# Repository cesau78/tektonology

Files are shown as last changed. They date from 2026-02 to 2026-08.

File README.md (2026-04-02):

# tektonology

A church maintenance system in progress: help parishes organize parishioners around upkeep and restoration. 3D printing is central—anyone can contribute printable parts and fixtures—alongside web tools, data, and local agents.

## Principles and conventions

- **[heuristic-imperatives.md](heuristic-imperatives.md)** — how we weigh tradeoffs (suffering, prosperity, understanding). Canonical copy for humans and tooling.
- **[CLAUDE.md](CLAUDE.md)** — JSON shape, repo layout, Next.js static export, languages.

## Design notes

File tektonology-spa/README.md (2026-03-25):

# Tektonology SPA

Next.js static site for [tektonology.com](https://tektonology.com) — a church/home maintenance asset tracker with 3D-printable solutions.

## Operations Data Model

All collection-level entities extend `Auditable` (`createdAt`, `updatedAt`, `deletedAt`).
Transactional entities carry an effective date separate from `createdAt` to support latent recording.

```mermaid
erDiagram
    Auditable {
        string createdAt "ISO 8601 — when recorded"
        string updatedAt "ISO 8601 — last modified"
        string deletedAt "ISO 8601 — soft delete"
    }

    Spool {
        number spoolId PK
        string brand
        string material
        string color
        string effective "when it occurred"
        number cost "fully-loaded"
        number weightG "starting grams"
        number remainingG
        number journalId FK
    }

    Printer {
        number printerId PK
        string brand
        string name
        string effective "when it occurred"
        number baseCost
        number taxes
        number shipping
        number cost "fully-loaded"
        number hoursUsed "cumulative"
        number journalId FK
    }

    Nozzle {
        number nozzleId PK
        string brand
        string nozzle "e.g. 0.4mm Stainless"
        string effective "when it occurred"
        number baseCost
        number taxes
        number shipping
        number cost "fully-loaded"
        number hoursUsed "cumulative"
        number journalId FK
    }

    Plate {
        number plateId PK
        string brand
        string plate "e.g. Textured PEI"
        string effective "when it occurred"
        number baseCost
        number taxes
        number shipping
        number cost "fully-loaded"
        number hoursUsed "cumulative"
        number journalId FK
    }

    PrintJob {
        string project
        PrintJobOutcome outcome "production|prototype|tooling|failed"
        number printerId FK
        number nozzleId FK
        number plateId FK
        number spoolId FK
        number usageG
        number hours "print duration"
        Component components "empty on failure"
        string effective "when it occurred"
        boolean processed
        number cost "usageG x rate"
        string processedAt "ISO 8601"
    }

    Component {
        number productId FK "optional for one-offs"
        string version "which version was printed"
        string stlUrl "STL file used"
        string part "e.g. Insert, Bushing"
        number quantity
    }

    Product {
        number productId PK
        string name "e.g. Kneeler Boot"
        string category
        string description
        ProductOrigin origin "original|third-party"
        string sourceUrl "third-party URL"
        string effective "when first created"
        Record printSettings "camelCase keys"
        string assemblyGuide "optional steps"
        ProductVersion versions "version history"
    }

    ProductVersion {
        string version "semver"
        string commit "GitHub SHA"
        string effective "when it occurred"
        string scadUrl "OpenSCAD source"
        ProductStl stls "STL files"
        string changelog
    }

    ProductStl {
        string label
        string url "path to STL"
        string color "hex color"
    }

    Inventory {
        number inventoryId PK
        string product "e.g. Compound Bonded Boot"
        string effective "when it occurred"
        InventoryComponent components "from print jobs"
        InventoryHardware hardware "optional fasteners etc"
        number quantity "total assembled"
        number remaining "after consumption"
    }

    InventoryComponent {
        string printJobId FK "MongoDB _id"
        string part "component part name"
        number quantity
    }

    InventoryHardware {
        number hardwareId FK
        string item
        number quantity
    }

    Project {
        number projectId PK
        string name "e.g. St Stanislaus Restoration"
        string client
        boolean proBono
        string effective "when it occurred"
        string status "active|completed|cancelled"
        ProjectItem items "inventory consumed"
        number journalId FK
    }

    ProjectItem {
        number inventoryId FK
        string product
        number quantity
    }

    Sale {
        number saleId PK
        string effective "when it occurred"
        string customer
        SaleItem items "inventory sold"
        number revenue
        number journalId FK
    }

    SaleItem {
        number inventoryId FK
        string product
        number quantity
        number unitPrice
        number amount "qty x unit price"
    }

    Account {
        number number PK "chart-of-accounts"
        string name
        AccountType type "asset|liability|equity|revenue|cogs|expense"
        number balance
    }

    JournalEntry {
        number transactionId PK
        string effective "when it occurred"
        string description
    }

    JournalLine {
        number accountNumber FK
        string accountName
        number debit "null if credit"
        number credit "null if debit"
    }

    Hardware {
        number hardwareId PK
        string supplier
        string supplierId
        string item
        string dimensions
        string material
        string effective "when it occurred"
        number baseCost
        number taxes
        number shipping
        number cost "fully-loaded"
        number quantity
        number remaining
        number journalId FK
    }

    Printer ||--o{ PrintJob : "runs on"
    Nozzle ||--o{ PrintJob : "prints with"
    Plate ||--o{ PrintJob : "builds on"
    Spool ||--o{ PrintJob : "tracks usage"
    Product ||--o{ Component : "designed as"
    Product ||--|{ ProductVersion : "versioned as"
    ProductVersion ||--|{ ProductStl : "includes files"
    PrintJob ||--|{ Component : "produces"
    PrintJob ||--o{ InventoryComponent : "supplies parts"
    Inventory ||--|{ InventoryComponent : "assembled from"
    Hardware ||--o{ InventoryHardware : "used in"
    Inventory ||--o{ InventoryHardware : "optionally includes"
    Inventory ||--o{ ProjectItem : "consumed by"
    Inventory ||--o{ SaleItem : "sold as"
    Project ||--|{ ProjectItem : "consumes"
    Sale ||--|{ SaleItem : "contains"
    JournalEntry ||--o{ Spool : "proves COGS"
    JournalEntry ||--o{ Nozzle : "proves purchase"
    JournalEntry ||--o{ Plate : "proves purchase"
    JournalEntry ||--o{ Printer : "proves purchase"
    JournalEntry ||--o{ Hardware : "proves purchase"
    JournalEntry ||--o{ Project : "records cost"
    JournalEntry ||--o{ Sale : "records revenue"
    Account ||--o{ JournalLine : "debited/credited"
    JournalEntry ||--|{ JournalLine : "contains lines"
```

### Lifecycle

1. **Print** — Printing agent detects completion via MQTT, writes a `PrintJob` with printer/nozzle/plate/spool refs and `components[]` produced (phase 1: `processed: false`)
2. **Cost** — Accounting agent calculates filament cost, accumulates hours on printer/nozzle/plate, creates a balanced `JournalEntry`, marks job `processed: true`
3. **Inventory** — Components from print jobs + hardware are assembled into `Inventory` items (finished goods)
4. **Consume** — `Project` (custom orders, restorations, pro-bono) or `Sale` reduces inventory, each linked to a `JournalEntry` for COGS/revenue recognition
5. **Approve** — Print proxy (optional) intercepts jobs for approval before they reach the printer

## Development

```bash
npm run dev
```

Static export only (`output: "export"`) — no server-side runtime. Product and batch data lives in `data/` as JSON, loaded at build time via `readFileSync`.

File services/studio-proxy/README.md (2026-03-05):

# Studio Proxy

MITM MQTT proxy that intercepts Bambu Studio's cloud MQTT traffic
(`us.mqtt.bambulab.com`). Logs all messages and optionally blocks print
commands before relaying them to the real cloud server.

## Prerequisites

### 1. TLS Certs

Reuses certs from `services/print-proxy/certs/`. Generate them if needed:

```
npm run rotate-certs
```

### 2. Environment Variables

Shared vars (`MONGODB_URI`) come from the root `.env`.

Optional service-specific override in `services/studio-proxy/.env`:

```
STUDIO_PROXY_PORT=28883   # default 28883
```

### 3. Network Redirect (Windows)

Studio connects to the Bambu cloud MQTT server by IP (`34.208.11.28:8883`).
To intercept this traffic, add the cloud IP as a local alias and redirect
it to the proxy.

**Open an admin terminal** and run:

```powershell
# Add Bambu cloud IP as a local alias
netsh interface ipv4 add address "Ethernet" 34.208.11.28 255.255.255.0

# Redirect cloud:8883 → localhost:28883 (where studio-proxy listens)
netsh interface portproxy add v4tov4 listenaddress=34.208.11.28 listenport=8883 connectaddress=127.0.0.1 connectport=28883
```

Replace `"Ethernet"` with your network adapter name if different (run
`Get-NetAdapter` in PowerShell to check).

**To remove** when done:

```powershell
netsh interface portproxy delete v4tov4 listenaddress=34.208.11.28 listenport=8883
netsh interface ipv4 delete address "Ethernet" 34.208.11.28
```

**To verify** the redirect is active:

```powershell
netsh interface portproxy show all
```

## Usage

From the repo root:

```
npm run start:studio-proxy
```

When Studio sends a print command through the cloud, the proxy prompts for
approval in the terminal:

```
[studio-proxy] PRINT JOB DETECTED: "my-model.3mf"
Approve print job "my-model.3mf"? [y/N]
```

Type `y` to forward to the cloud, or anything else to block.

## How It Works

```
Bambu Studio ──MQTTS──▸ Studio Proxy:28883 ──MQTTS──▸ us.mqtt.bambulab.com:8883
                             │                              │
                             ◂────────── responses ─────────┘
                             │
                         [approve/block]
```

- Studio thinks it's connecting to the cloud (IP alias + port forward)
- Proxy accepts Studio's credentials and uses them to connect upstream
- All MQTT messages are logged to MongoDB (`studio_mqtt_log` collection)
- Print-start commands (`project_file`, `gcode_file`, `print_3mf`) trigger
  an interactive approval prompt

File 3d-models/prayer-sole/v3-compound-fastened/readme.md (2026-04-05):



# Prayer Sole — v3 compound fastened
This folder contains the Tektonology Prayer Sole fastened system: a rigid PLA **collar** shell, a soft TPU **tread**, and a **cap**, assembled with mechanical fasteners (no glue required for the v3 fastener design).

### Print settings (Bambu A1)
* **Collar:** Polymaker PLA Pro (Black) | 4 Wall Loops | 35% Gyroid Infill.
* **Tread:** TPU 90A | 4 Wall Loops | 35% Gyroid Infill | Print Speed < 40mm/s.

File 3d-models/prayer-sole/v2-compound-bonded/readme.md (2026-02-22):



# Kneeler Boot - Compound Bonded
This folder contains the Tektonology compound bonded boot system. It uses a rigid upper shell for stability and a soft lower pad for grip, assembled with adhesive.

### Print Settings (Bambu A1)
* **Upper Boot:** Polymaker PLA Pro (Black) | 4 Wall Loops | 35% Gyroid Infill.
* **Floor Pad:** TPU 90A | 4 Wall Loops | 4 Wall Loops | 35% Gyroid Infill | Print Speed < 40mm/s.

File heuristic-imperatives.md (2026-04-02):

# Heuristic imperatives

When making decisions — about design, naming, architecture, or implementation — apply these **without order or priority**:

1. **Reduce Suffering** — prefer solutions that remove friction, eliminate toil, and avoid creating problems for people downstream.
2. **Increase Prosperity** — prefer solutions that create lasting value, are reusable, and support the project's mission.
3. **Increase Understanding** — prefer solutions that are clear, well-named, and easy to reason about over clever or opaque ones.

This file is the **canonical** copy. [CLAUDE.md](CLAUDE.md) summarizes project mechanics (JSON, directories, Next.js); the Cursor rule `.cursor/rules/tektonology-imperatives.mdc` points here so assistants load the same bar.

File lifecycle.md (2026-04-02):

# Tektonology Church Maintenance Lifecycle

This lifecycle describes how Tektonology helps a church maintain its spaces, tools, and fixtures through a transparent, repeatable process powered by parishioner participation.

Each phase includes roles that parishioners can sign up for based on their gifts, time, and resources.

## Phase 1: Stewardship Funding

**Role: Philanthropists**

Philanthropists seed and sustain a dedicated maintenance fund.

- Contribute financial support to the maintenance pool.
- Enable predictable repair and replacement work instead of emergency-only fixes.
- Support a transparent ledger that is publicly viewable in an anonymous format.

## Phase 2: Issue Spotting and Reporting

**Role: Spotters**

Spotters identify maintenance needs and submit clear field reports.

1. Take a maintenance tag from a QR station.
2. Wrap or attach the tag to the broken item or area that needs attention.
3. Scan the tag's code with a phone.
4. Capture a photo and submit a short issue report.
5. Send the report into a review queue for approval and prioritization.

## Phase 3: Repair and Fabrication

**Role: Tektons**

Tektons provide the craftsmanship and technical labor needed to complete approved work.

- Evaluate approved requests and define the repair plan.
- Repair, replace, fabricate, or otherwise maintain the affected item.
- Document work completion so the maintenance history remains traceable.
- Return the maintenance tag to the QR station so it can be reused for future issues.

## Phase 4: Accountability and Continuity

**Shared Roles: Philanthropists, Spotters, Tektons**

All roles reinforce long-term sustainability.

- Funding activity remains transparent and trusted.
- Completed work is logged for future reference.
- New issues cycle back into the spotting phase.
- The church maintains a living, maintainable maintenance schedule.

---

## Notes for Future Infographics

- **Two connected rings:** (1) **Restoration lifecycle** (on site): Spot → Prepare → Restore; hub label “Restore.” (2) **Planning lifecycle** (getting what you need for restoration): Fund → R&D → Make & procure. Bridge copy connects field restoration to funding, design, and supply.
- Highlight role sign-up points at each phase.
- Show how transparency and documentation connect every stage.

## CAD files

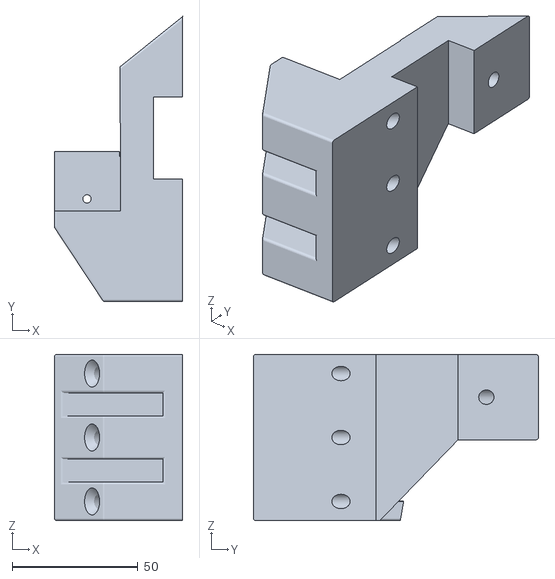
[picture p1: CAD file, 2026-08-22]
3d-models/bumper-bracket/latest-builds/v2.4/bumper-bracket-assembly-shell.stl
51.1 x 113.4 x 66.2

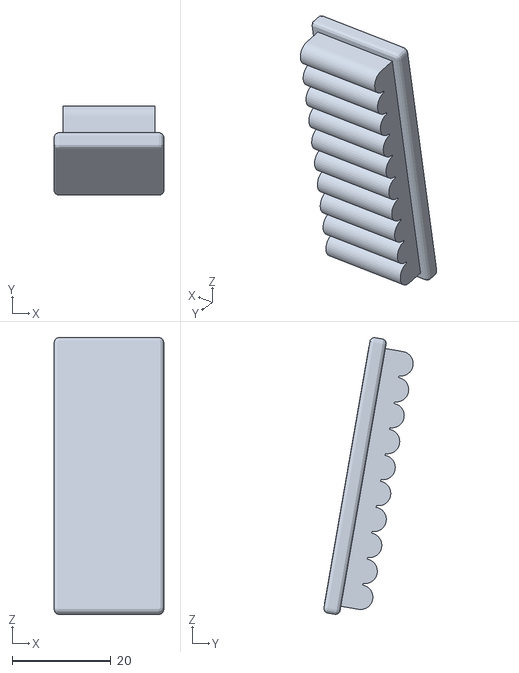
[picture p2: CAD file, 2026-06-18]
tektonology-spa/public/stl/bumper-bracket-assembly-tread-1.stl
22.2 x 18.2 x 56.2

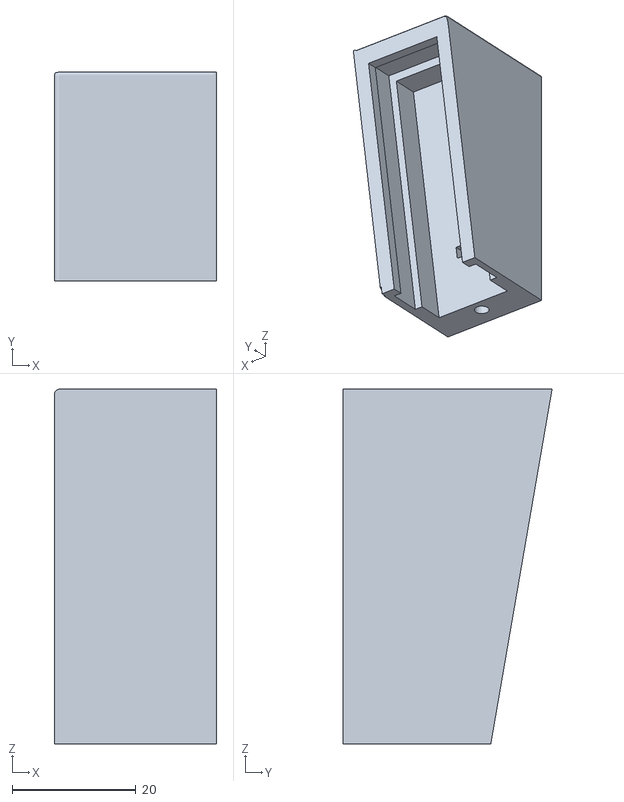
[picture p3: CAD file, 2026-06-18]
tektonology-spa/public/stl/bumper-bracket-assembly-carriage.stl
26.2 x 33.9 x 57.5

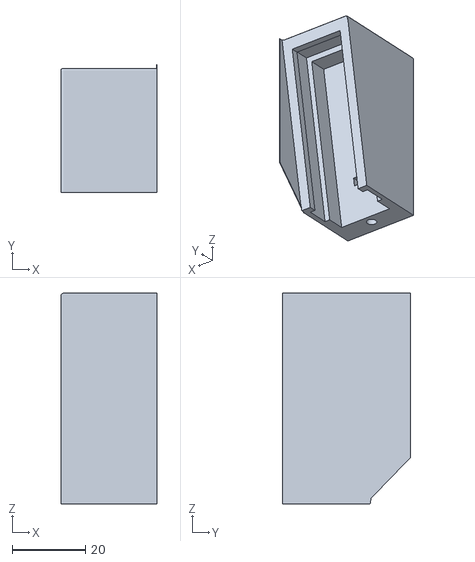
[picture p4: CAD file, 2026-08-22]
3d-models/bumper-bracket/latest-builds/v2.4/bumper-bracket-assembly-carriage.stl
26.2 x 35.0 x 57.5

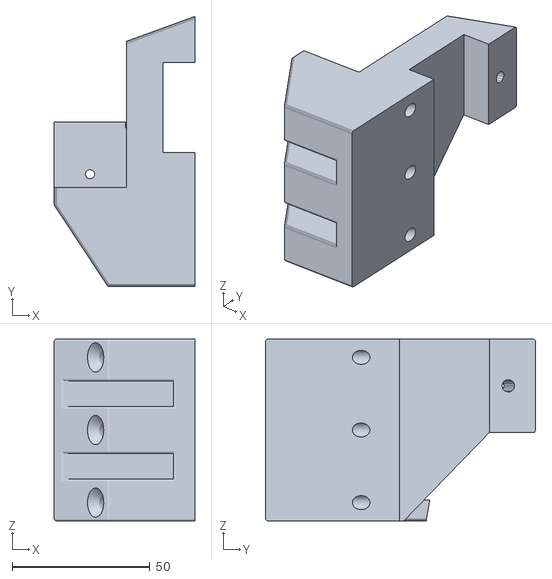
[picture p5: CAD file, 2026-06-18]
tektonology-spa/public/stl/bumper-bracket-assembly-shell.stl
51.1 x 98.2 x 66.2

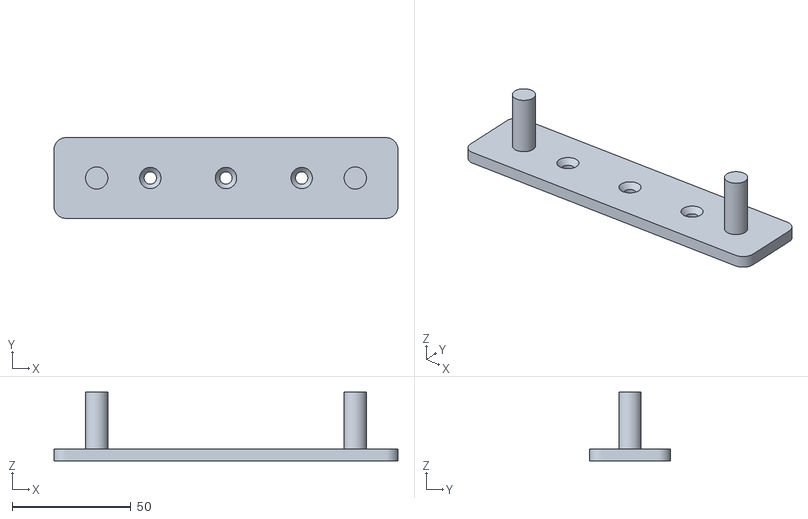
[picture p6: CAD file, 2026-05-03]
3d-models/kneeler-bracket/kneeler-bracket-left.stl
145.0 x 34.0 x 29.0

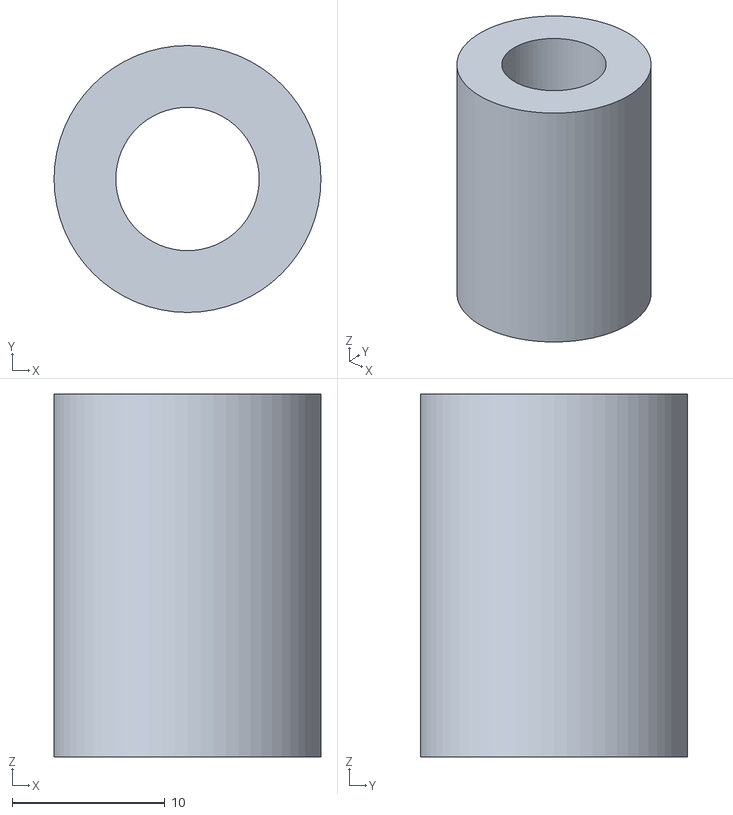
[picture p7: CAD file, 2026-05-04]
3d-models/kneeler-bumper/kneeler-bumper.stl
17.5 x 17.5 x 23.8

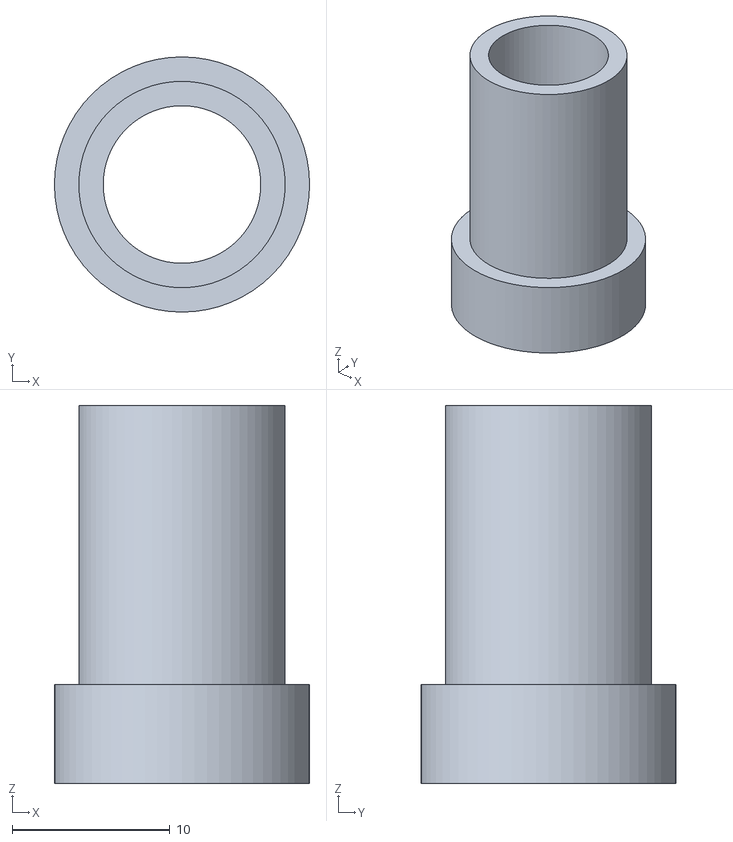
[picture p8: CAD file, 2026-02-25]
3d-models/kneeler-bushing/kneeler-bushing.stl
16.2 x 16.2 x 24.0

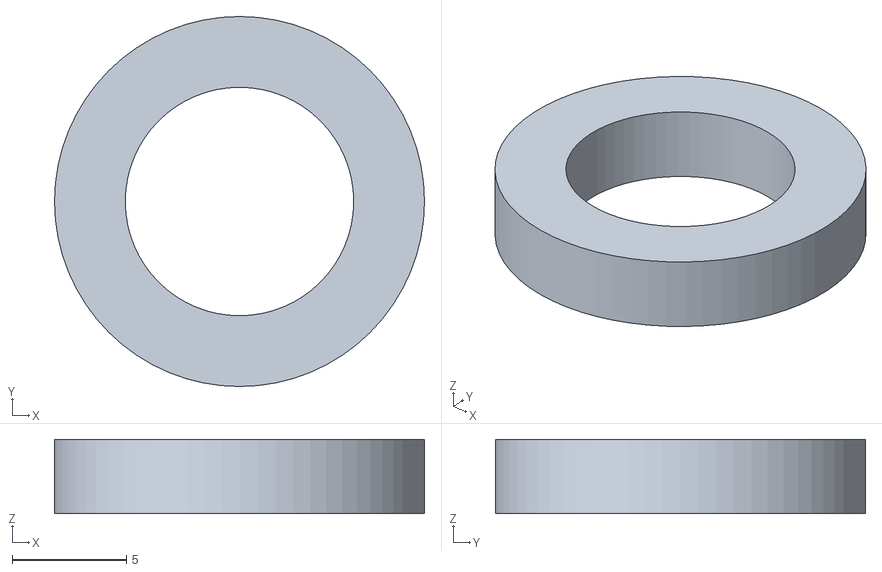
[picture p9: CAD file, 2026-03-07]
3d-models/kneeler-spacer/kneeler-spacer.stl
16.2 x 16.2 x 3.25

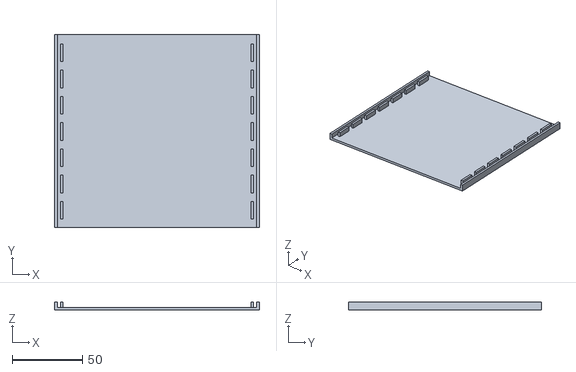
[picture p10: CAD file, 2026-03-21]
3d-models/notecard-holder/notecard-holder-bottom.stl
146.4 x 138.0 x 6.00

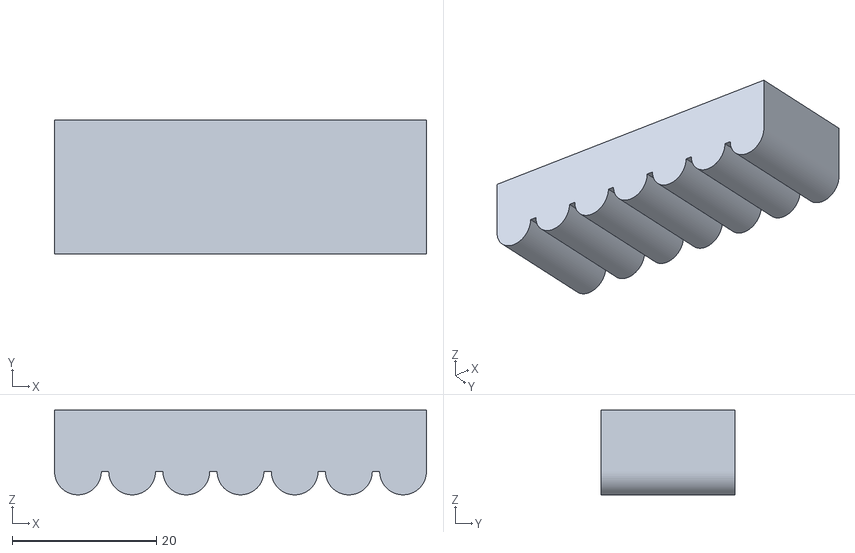
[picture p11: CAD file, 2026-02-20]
3d-models/prayer-sole/v2-compound-bonded/kneeler-boot-insert.stl
51.6 x 18.6 x 11.8

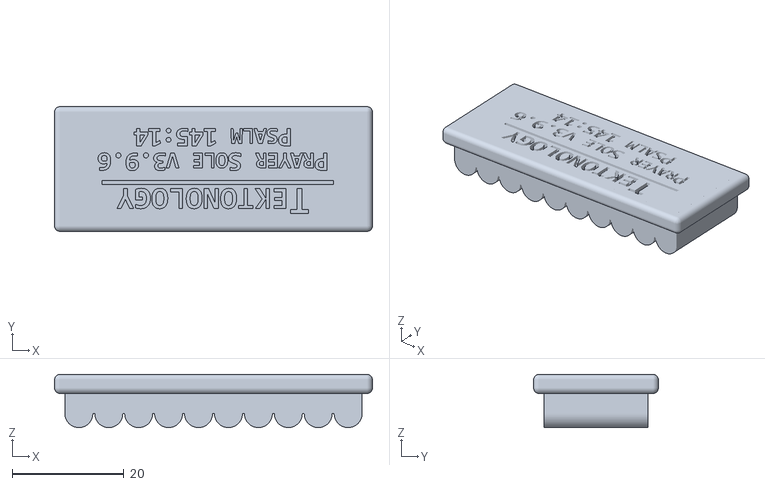
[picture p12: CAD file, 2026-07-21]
3d-models/prayer-sole/v3-compound-fastened/latest-builds/v3.9.6/tread.stl
56.8 x 22.3 x 9.50

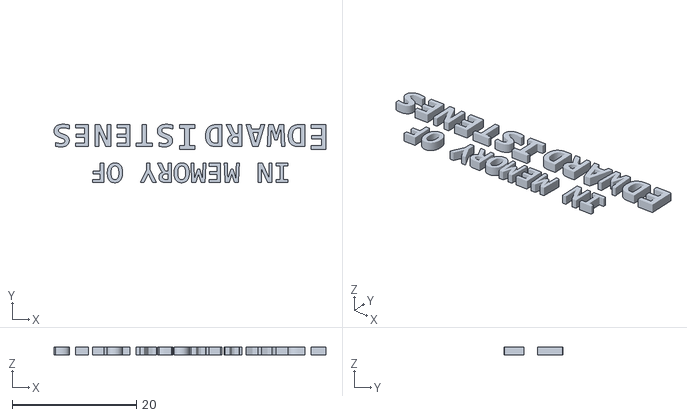
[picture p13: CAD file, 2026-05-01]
3d-models/prayer-sole/v3-compound-fastened/sole-prayers/edward-istenes/edward-istenes-tread-text.stl
43.8 x 9.44 x 1.21

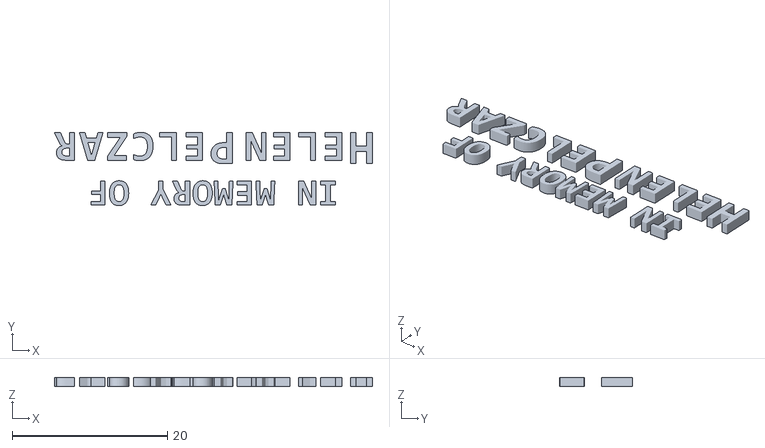
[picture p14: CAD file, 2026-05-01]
3d-models/prayer-sole/v3-compound-fastened/sole-prayers/helen-pelczar/helen-pelczar-tread-text.stl
40.9 x 9.43 x 1.21

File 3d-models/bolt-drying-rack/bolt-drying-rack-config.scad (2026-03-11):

// --- TEKTONOLOGY BOLT DRYING RACK CONFIG ---
// Shared parameters for drying rack plates and legs.

tolerance     = 0.15;    // general clearance per side (mm)

// --- Bolt Profile: M3x20 Socket Head Cap Screw ---
bolt_dia        = 3.0;    // shaft diameter (mm)
bolt_length     = 20;     // shaft length under head (mm)
bolt_clearance  = 0.3;    // radial clearance for bolt holes (mm)
head_dia        = 6.0;    // socket head cap diameter (mm)
head_height     = 3.5;    // socket head height (mm)

// --- Plate Parameters ---
cols          = 25;     // bolts per plate
rows          = 2;      // rows of bolts
spacing       = head_dia + bolt_clearance;  // center-to-center hole spacing (along X)
row_spacing   = spacing * sin(60);          // tighter Y spacing for hex packing
plate_thick   = 2;      // plate thickness (mm)
edge_margin   = 4;      // margin from outermost hole to plate edge

// Hole diameter: shaft passes through, head rests on top plate
// Head margin: (head_dia - hole_dia) / 2 = 1.2mm per side resting on plate
hole_dia      = bolt_dia + bolt_clearance * 2;

// --- Derived plate dimensions ---
stagger       = spacing / 2;                                    // row-1 X offset for staggered pattern
pattern_x     = (cols - 1) * spacing + stagger;                 // combined hole pattern width
tab_length    = spacing;                                        // solid margin on each end for leg channels
plate_x       = pattern_x + (edge_margin * 2) + (tab_length * 2);  // plate length
plate_y       = (rows - 1) * row_spacing + (edge_margin * 2);  // plate width
hole_x0       = tab_length + edge_margin;                       // first hole X (row 0)

// End-stop flange at -X end of plate: taller than channel slot, blocks slide-through
stop_width    = 1;      // flange width along X
stop_extra    = 1;      // how much taller than plate_thick (must exceed slot clearance)

// --- Two-plate hanging geometry ---
compound_length = bolt_length / 4;                             // 1/4 shaft sticks below bottom plate
shaft_below_top = bolt_length - plate_thick;                  // shaft below top plate
plate_gap       = shaft_below_top - plate_thick - compound_length; // vertical gap between plates

// Heights (Z positions of plate bottom surfaces)
clearance_mm    = 25.4;                                       // bolt tip ~1 inch above ground
bottom_plate_z  = clearance_mm + compound_length ; // bottom plate Z (backed off by tolerance)
top_plate_z     = bottom_plate_z + plate_thick + plate_gap; // top plate Z (backed off by tolerance)

// --- Leg / Channel Parameters ---
channel_wall  = 2.5;    // wall thickness on Y sides of each channel
leg_post_x    = 2;      // leg thickness along X (plate slide direction)
detent_h      = 0.4;    // snap detent height — ceiling only (must be >= 1 layer height)
detent_w      = 1.0;    // detent width along X (slide direction)

// Derived leg dimensions
slot_h        = plate_thick + tolerance * 2;   // slot height (Z)
slot_y        = plate_y + tolerance * 2;       // slot width (Y) — plate fits inside
leg_post_y    = slot_y + channel_wall * 2;    // total leg Y width
total_height  = top_plate_z + plate_thick + channel_wall; // leg total height

// --- Y-branch (inverted Y) ---
split_z       = total_height / 2;                  // Z where post splits into two branches
splay_angle   = 30;                                // degrees from vertical
splay         = split_z * tan(splay_angle);        // Y offset of each foot from center
foot_w        = leg_post_x;                        // foot pad width (X)
foot_d        = leg_post_y;                        // foot pad depth (Y) — same as post

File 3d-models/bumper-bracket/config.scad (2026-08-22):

// ─────────────────────────────────────────────────────────────────────────────
// Bumper bracket — shared configuration.
//
// Shell envelope (core + roof wedge + pew mount pad) sized to the kneeler and
// tread envelopes, with #8 wood-screw bores through the roof wedge.
//
// This file is split into two halves:
//   1. PARAMETERS   — every plain `name = value;` declaration, grouped by domain.
//   2. FUNCTIONS    — every `function name() = ...;` derivation, grouped to match.
// OpenSCAD resolves the whole file as one scope, so the split is purely for
// readability; nothing here depends on top-to-bottom ordering.
//
// Bracket coordinate frame (the design frame for bumper-bracket.scad; the body is
// never rotate()-reoriented — bracket_lift_to_bed only translates +Z for export):
//   Origin : footprint center.
//   +X     : QR / kneeler side (−X) toward the wedge and sloped roof (+X rim).
//   +Y     : shell height toward the roof / wedge apex (lower Y = higher up).
//   +Z     : pew engagement (+Z rim); the tread slot opens toward −Z.
// Sizing helpers (lx, ly, lz) use a corner-origin box; bracket_pos() maps those
// into the centered bracket frame.
//
// Face labels (debug preview):
//   A = +X prism / wedge rim     B = −X opposite (narrow) rim
//   C = +Z pew engagement        D = −Z tread slot
//   E = +Y base (sizing lz → 0)  F = −Y roof / wedge apex
// ─────────────────────────────────────────────────────────────────────────────

// ═══════════════════════════════════════════════════════════════════════════
//  PARAMETERS
// ═══════════════════════════════════════════════════════════════════════════

// ── Global render / build ────────────────────────────────────────────────────
preview             = true;
epsilon             = 0.02;   // manifold fudge for booleans + thin slabs
corner_r            = 1;      // exterior fillet radius (minkowski sphere)
bracket_lift_to_bed = true;   // export: translate so min Z sits on the build plate
// Rectangular "hull" cutters are hulls of cubes this size CENTERED on the nominal
// corner points, so every hull cutter overshoots its nominal bounds by half this.
HULL_VERTEX_CUBE_MM = 0.5;

// ── Kneeler-bracket reference (keep in sync with kneeler-bracket-visual.scad) ─
kneeler_bracket_plate_thickness_mm   = 5;
kneeler_bracket_plate_l_mm           = 145;
kneeler_bracket_plate_w_mm           = 32;
kneeler_bracket_corner_r_mm          = 5;
kneeler_bracket_peg_od_mm            = 9.4;
kneeler_bracket_peg_top_from_base_mm = 44.5;  // plate bottom (z = 0) → peg top
kneeler_bracket_peg_h_mm             = kneeler_bracket_peg_top_from_base_mm - kneeler_bracket_plate_thickness_mm;
kneeler_bracket_peg1_inset_mm        = 18;
kneeler_bracket_peg2_inset_mm        = 18;     // far peg from +lx rim (bumper peg)
kneeler_bracket_support_h_mm         = 19.5;   // plate bottom → top of peg boss
kneeler_bracket_support_od_mm        = 16;
kneeler_bracket_screw_d_mm           = 5.2;
kneeler_bracket_csink_d_mm           = 10.5;
kneeler_bracket_csink_depth_mm       = 2.5;
kneeler_bracket_screw_x_frac         = [0.28, 0.5, 0.72];
kneeler_bracket_mirror_side          = false;  // false = left, true = right (Y mirror)

// ── Kneeler-bushing reference (keep in sync with kneeler-bushing-visual.scad) ─
kneeler_bushing_total_height_mm  = 24;
kneeler_bushing_id_mm            = 10;
kneeler_bushing_insert_od_mm     = 13.1;
kneeler_bushing_collar_height_mm = 6.3;
kneeler_bushing_collar_od_mm     = 16.2;

// ── Kneeler-bumper reference (keep in sync with kneeler-bumper-visual.scad) ───
kneeler_bumper_height_mm    = 23.8;
kneeler_bumper_od_mm        = 17.5;
kneeler_bumper_peg_od_mm    = 9.7;
kneeler_bumper_tightness_mm = 0.3;
kneeler_bumper_id_mm        = kneeler_bumper_peg_od_mm - kneeler_bumper_tightness_mm;

// ── Kneeler-arm reference (keep in sync with kneeler-arm-visual.scad) ─────────
kneeler_arm_length_mm     = 108;
kneeler_arm_h1_mm         = 34;
kneeler_arm_h2_mm         = 20;
kneeler_arm_thickness_mm  = 18.6;
kneeler_arm_peg_d_mm      = 20;
kneeler_arm_peg_hole_d_mm = 13.8;

// ── Tread / sole reference (keep in sync with prayer-sole v3 tread.scad) ──────
tread_tightness            = 0.1;   // tolerance from tread.scad
sole_plate_l               = 53;
sole_plate_w               = 18.5;
groove_overhang            = 2;
socket_depth               = 5;
core_protrusion            = 2;
flange_clearance           = 0.2;
tread_flange_envelope_z_mm = 3.4;   // minkowski flange height (cube + 2×sphere)
tread_visual_flange_sphere_r = 1.0;
flange_depth               = tread_flange_envelope_z_mm - 2 * tread_visual_flange_sphere_r;  // 1.4 mm cube → 3.4 mm envelope

// Derived tread geometry.
tread_l            = sole_plate_l + tread_tightness;
tread_w            = sole_plate_w + tread_tightness;
core_depth         = socket_depth + core_protrusion;
tread_rib_radius_mm = socket_depth / 2;   // rib cylinder radius (was "radius")
// Conservative tread vertical span (core + ribs + flange minkowski).
tread_z_span_mm    = (socket_depth / 2 + core_depth / 2) - (-core_protrusion / 2 - tread_rib_radius_mm)
                     + flange_depth + 4;

// Tread slide-in groove footprint (tread.scad).
groove_l = sole_plate_l + (groove_overhang * 2) - flange_clearance;
groove_w = sole_plate_w + (groove_overhang * 2) - flange_clearance;

// ── Exterior sizing rules ────────────────────────────────────────────────────
side_margin_each_mm    = 0.5 * 25.4;   // ½" added on each side of the tread Z span
width_extra_half_tread = true;         // add ½ tread width along the QR↔wedge extent
// Pew engagement depth along +Y (shell_face_pew at y = shell_extent_tread_pew_mm).

// ── Shell + wedge: overall extents ───────────────────────────────────────────
// Right-triangle roof prism on the roof–rim section: 90° at the inset corner,
// 52.5° at the roof, 37.5° at the rim. Apex rises toward the +X rim and lower Y.
shell_wedge_prism_roof_angle_deg = 52.5;

shell_extent_qr_wedge_mm  =
    kneeler_bracket_plate_thickness_mm + kneeler_bumper_height_mm + (width_extra_half_tread ? tread_w / 2 : 0);
shell_z_inset_mm          = 5;           // trim both +Z (face C) and −Z (face D) by this amount
shell_extent_tread_pew_mm = 3 * 25.4 - 2 * shell_z_inset_mm;   // 3" pew engagement along +Y
shell_height_mm           = tread_z_span_mm + 2 * side_margin_each_mm;

// Wedge run / leg (leg comes from the roof angle, not a fixed height).
shell_inset_dim_qr_wedge_mm   = shell_extent_qr_wedge_mm - 2 * corner_r;
shell_inset_dim_tread_pew_mm  = shell_extent_tread_pew_mm - 2 * corner_r;
shell_wedge_hypotenuse_run_mm = shell_inset_dim_qr_wedge_mm;
shell_wedge_leg_mm            = shell_wedge_hypotenuse_run_mm * tan(shell_wedge_prism_roof_angle_deg);

// ── Bracket frame: mid planes + face positions ───────────────────────────────
shell_midplane_lz_mm = shell_height_mm / 2;   // sizing axis mid (lz)
bracket_nat_y_mid_mm = (shell_height_mm + shell_wedge_leg_mm + corner_r) / 2;
shell_midplane_y_mm  = bracket_nat_y_mid_mm - shell_midplane_lz_mm;

bracket_face_tread_slot_z_mm = -shell_extent_tread_pew_mm / 2;  // D (−Z mouth)
bracket_face_pew_z_mm        =  shell_extent_tread_pew_mm / 2;  // C (+Z pew)
bracket_face_wedge_x_mm      =  shell_extent_qr_wedge_mm / 2;   // A (+X rim)

// ── Shell envelope anchors (pre-minkowski union: core + roof wedge + pew pad) ─
// shell_envelope_inset_lx_mm: −X face of the pre-mink core (lx sizing coords).
// = corner_r (minkowski inset) + any extra trim on the −X side.
// Increasing this moves the −X face (face B) inward without touching the +X rim.
shell_envelope_inset_lx_mm = corner_r + 5;
shell_envelope_inset_ly_mm = corner_r;
shell_envelope_roof_lz_mm  = shell_height_mm;
shell_envelope_apex_lz_mm  = shell_height_mm + shell_wedge_leg_mm;
// core_lx spans from the (possibly trimmed) −X inset to the fixed +X rim (shell_extent − corner_r).
shell_envelope_core_lx_mm  = shell_extent_qr_wedge_mm - corner_r - shell_envelope_inset_lx_mm;
shell_envelope_core_ly_mm  = shell_inset_dim_tread_pew_mm;
shell_envelope_core_lz_mm  = shell_height_mm - corner_r;

// ── E-bevel (side D, −Z tread slot) ──────────────────────────────────────────
// 9.8° bevel: C∩E flush, D∩E inset; D∩F stays 90°.
tread_face_de_extra_angle_deg = 9.8;
// Y inset at D∩E for the nominal C↔D span (≈12.8 mm at the default depth).
tread_face_d_e_side_y_narrow_mm = tan(tread_face_de_extra_angle_deg) * shell_extent_tread_pew_mm;
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

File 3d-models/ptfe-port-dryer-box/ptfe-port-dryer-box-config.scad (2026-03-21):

// PTFE Dryer Box Port — Shared Configuration

// Performance
preview = false;
$fn = preview ? 32 : 64;

// PTFE tube dimensions (standard 1.75mm filament tube)
ptfe_od        = 4.0;   // outer diameter of PTFE tube
ptfe_clearance = 0.1;   // clearance per side for snug push-fit
hole_dia       = ptfe_od + ptfe_clearance * 2;

// Dryer box wall
dryer_box_thickness = 6.5; // mm — wall thickness of the dryer box

// Filament port — angled section outside the wall where PTFE tube inserts
channel_angle  = 45;    // degrees upward from horizontal
port_dia       = 12.0;  // outer diameter of filament port
socket_depth   = 8.0;   // how far PTFE tube inserts into port
flare_dia      = hole_dia * 2.5; // chamfered opening diameter at tip
flare_depth    = 3.0;            // depth of the chamfer cone

// Wall plug — straight cylinder perpendicular through dryer box wall
plug_dia       = 8.0;   // outer diameter (match drill bit)
plug_z_offset  = 2.0;   // vertical offset to align with filament port

// Flange — vertical disc flush against outside wall surface
flange_dia     = 14.0;  // outer diameter of flange
flange_thick   = 2.0;   // flange thickness

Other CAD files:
3d-models/bumper-bracket/latest-builds/v2.4/bumper-bracket-assembly-tread-2.stl
tektonology-spa/public/stl/bumper-bracket-assembly-tread-2.stl
3d-models/bumper-bracket/latest-builds/v2.4/bumper-bracket-assembly-tread-1.stl
3d-models/bumper-bracket/latest-builds/v2.4/tread-carriage-left.stl
3d-models/notecard-holder/notecard-holder-config.scad
3d-models/allen-wrench-handle/allen-wrench-handle.scad
3d-models/bolt-drying-rack/bolt-drying-rack-assembled-bolts.stl
3d-models/bolt-drying-rack/bolt-drying-rack-assembled-rack.stl
3d-models/bolt-drying-rack/bolt-drying-rack-leg.scad
3d-models/bolt-drying-rack/bolt-drying-rack-plate.scad
3d-models/bolt-drying-rack/bolt-drying-rack.scad
3d-models/bumper-bracket/assembly-export.scad
3d-models/bumper-bracket/assembly.scad
3d-models/bumper-bracket/bumper-bracket-right.scad
3d-models/bumper-bracket/bumper-bracket.scad
3d-models/bumper-bracket/cap.scad
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

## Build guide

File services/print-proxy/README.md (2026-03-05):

# Print Proxy

MITM MQTT proxy that sits between Bambu Studio and your printer. Intercepts
print commands for approval before forwarding them to the real printer, and
relays telemetry back to Studio.

## Prerequisites

### 1. Generate TLS Certs

From the repo root:

```
npm run rotate-certs
```

Certs are written to `services/print-proxy/certs/` (gitignored). Rotate
anytime — the proxy hot-reloads certs without restarting.

### 2. Environment Variables

Shared vars (`PRINTER_IP`, `PRINTER_SERIAL`, `PRINTER_ACCESS_CODE`) come from
the root `.env`. Copy `.env.example` to `.env` if you haven't already.

Optional service-specific override in `services/print-proxy/.env`:

```
PROXY_PORT=8883   # default 8883
```

### 3. Network Redirect (Windows)

Bambu Studio discovers printers via SSDP and connects to their real LAN IP.
It doesn't support manually entering a proxy address. To route Studio's traffic
through the proxy, we add the printer's IP as a local alias and use port
forwarding to redirect traffic to the proxy.

The proxy must listen on a **different port** (e.g. `18883`) so it can still
reach the real printer on `8883` without looping back to itself. Set
`PROXY_PORT=18883` in `services/print-proxy/.env`.

**Open an admin terminal** and run:

```powershell
# Add the printer IP as a local alias so Windows accepts connections to it
netsh interface ipv4 add address "Ethernet" <PRINTER_IP> 255.255.255.0

# Redirect printer IP:8883 → localhost:18883 (where the proxy listens)
netsh interface portproxy add v4tov4 listenaddress=<PRINTER_IP> listenport=8883 connectaddress=127.0.0.1 connectport=18883
```

Replace `<PRINTER_IP>` with your printer's actual IP (e.g., `192.168.20.69`).
Replace `"Ethernet"` with your network adapter name if different (run
`Get-NetAdapter` in PowerShell to check).

**To remove** when done:

```powershell
netsh interface portproxy delete v4tov4 listenaddress=<PRINTER_IP> listenport=8883
netsh interface ipv4 delete address "Ethernet" <PRINTER_IP>
```

**To verify** the redirect is active:

```powershell
netsh interface portproxy show all
```

### 4. Windows Firewall

If Studio still can't connect, allow inbound traffic on port 8883:

```powershell
netsh advfirewall firewall add rule name="Print Proxy MQTTS" dir=in action=allow protocol=TCP localport=8883
```

To remove later:

```powershell
netsh advfirewall firewall delete rule name="Print Proxy MQTTS"
```

## Usage

From the repo root:

```
npm run start:print-proxy
```

When Studio sends a print command, the proxy prompts for approval in the
terminal:

```
[proxy] PRINT JOB DETECTED: "my-model.3mf"
Approve print job "my-model.3mf"? [y/N]
```

Type `y` to forward to the printer, or anything else to block.

## How It Works

```
Bambu Studio ──MQTTS──▸ Print Proxy ──MQTTS──▸ Printer
                           │                      │
                           ◂──────── reports ──────┘
                           │
                       [approve/block]
```

- Studio connects to proxy (thinks it's the printer)
- Proxy relays Studio commands to the real printer after inspection
- Printer telemetry flows back through proxy to Studio
- Print-start commands (`project_file`, `gcode_file`, `print_3mf`) trigger
  an interactive approval prompt

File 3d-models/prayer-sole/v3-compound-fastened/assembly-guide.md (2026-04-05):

# Assembly Guide
1. **Clean surfaces:** Remove any stringing from the internal wedge cavity.
2. **Press-fit:** Press the TPU tread into the PLA cavity until flush.
3. **Slide** the assembly onto the kneeler leg.
4. **Secure** with the included fastener — no adhesive needed.

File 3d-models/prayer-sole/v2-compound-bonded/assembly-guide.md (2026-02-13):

# Assembly Guide
1. **Clean Surfaces:** Remove any stringing from the internal wedge cavity.
2. **Apply Glue:** Place 2-3 drops of Loctite 406 inside the PLA upper boot cavity.
3. **Press-Fit:** Press the TPU floor pad wedge into the PLA cavity until flush.
4. **Cure:** Let sit for 60 seconds before installing on the pew.

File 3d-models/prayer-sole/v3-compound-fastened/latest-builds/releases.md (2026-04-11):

# Prayer Sole v3 (compound fastened) — `latest-builds`

STL exports for the fastened Prayer Sole system (TPU tread + PLA collar shell + cap). The tread stamp is driven by `stamp-config.json` (or another JSON you pass to the export script): line 1 = **`brand_name`** (e.g. **Tektonology**, large); optional line 2 = **`product_name`** (leave empty to skip; lines 3–4 compact upward); with **`stamp_show_version_line`** `false`, line 3 = **`stamp_line3`** (e.g. **Foundation v3.8.1**); line 4 = **`stamp_line4`** (e.g. **Psalm 145:14**, tertiary).

## Layout

- **`v3.x.y/`** — production exports: `KBCF_PRODUCTION=1`, OpenSCAD **`preview=false`**, **`$fn=128`** (slow mesh).
- **`v3.x.y-prototype/`** — local default and first CI step: no `KBCF_PRODUCTION`, uses **`stamp-config.json` → `preview`** (committed default **`true`**), **`$fn=32`**, faster STLs.

GitHub Actions on **push to `main`** runs prototype export, a smoke render, then production export. **Manual workflow** can skip production via the dispatch input.

See **`releases.md`** in each version folder for commit/tag notes when present.

## Stamp orientation

The TPU **tread** carries a debossed stamp on its **top** face (the flat that faces into the coupler), hidden after assembly.

## Export

From `3d-models/prayer-sole/v3-compound-fastened`:

- **PowerShell:** `.\scripts\Export-OpenScadStl.ps1`
- **Bash:** `./scripts/export-open-scad-stl.sh`

Optional config: pass path to a JSON with the same shape as `stamp-config.json`.

## Artifacts (per version folder)

| File | Role |
|---|---|
| `tread.stl` | TPU tread (top-face stamp when enabled) |
| `collar.stl` | PLA collar half |
| `cap.stl` | PLA cap |

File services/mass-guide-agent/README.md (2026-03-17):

# mass-guide-agent

Generates printable Order of Mass pamphlets for the Catholic Ordinary Form (Roman Rite). Each pamphlet includes the day's proper readings, psalm, and season-specific rubrics baked into a print-ready HTML file.

## How It Works

1. Iterates over a date range (default: today + 30 days)
2. For each date, fetches the USCCB daily readings page
3. Parses the HTML to extract readings, psalm refrain, season, and liturgical color
4. Renders the data into the pamphlet template (`src/template.ts`)
5. Writes `order-of-mass-yyyy-mm-dd.html` to `tektonology-spa/app/info/instructions/catholicism/`

## Usage

```bash
npm install
npm run generate              # next 30 days
npm run generate -- --days 7  # custom range
```

## Status

The template and output pipeline are complete. The USCCB fetch + parse step is stubbed — it logs the URL for each date but does not yet scrape the readings. Next steps:

- Add `cheerio` (or similar) to parse USCCB response HTML
- Extract: designation, season, color, readings, psalm, gospel
- Handle weekdays (may have no second reading)
- Determine Sunday lectionary cycle (A/B/C) from year
- Add scheduling (cron / GitHub Actions) for automatic regeneration

## Output

Files land in:

```
tektonology-spa/app/info/instructions/catholicism/order-of-mass-2026-03-01.html
tektonology-spa/app/info/instructions/catholicism/order-of-mass-2026-03-02.html
...
```

Each file is a self-contained, print-ready HTML document (landscape, 2-column grid, front-and-back on one sheet).

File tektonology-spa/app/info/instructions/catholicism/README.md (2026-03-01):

# Catholicism — Order of Mass

Bringing clarity to the Catholic Mass by providing printable, date-specific pamphlets with all prayers, responses, and Scripture readings for each day's liturgy.

## What's Here

### Daily Pamphlets — `order-of-mass-yyyy-mm-dd.html`

Self-contained HTML files designed for print. Each pamphlet includes:

- All congregational prayers and responses (bold text = your part)
- The day's proper readings: First Reading, Responsorial Psalm, Second Reading, Gospel
- Liturgical season, color, and calendar designation (e.g., "Second Sunday of Lent")
- Season-specific rubrics (e.g., Gloria omitted during Lent, Alleluia replaced)

**Print instructions:** Open in a browser → Ctrl+P → Landscape → Print on both sides (flip on long edge). The 4-panel grid layout reads left-to-right, top-to-bottom per column. Fold in half for a pocket booklet.

### BPMN Diagram — `order-of-mass-bpmn.svg`

A high-level process diagram of the Ordinary Form (Roman Rite) Mass. Four swim lanes map the major phases:

| Phase | Key Activities |
|---|---|
| Introductory Rites | Entrance, Greeting, Penitential Act, Kyrie, Gloria (conditional), Collect |
| Liturgy of the Word | First Reading, Psalm, Second Reading, Gospel Acclamation, Gospel, Homily, Creed, Universal Prayer |
| Liturgy of the Eucharist | Preparation, Preface, Sanctus, Eucharistic Prayer, Lord's Prayer, Sign of Peace, Communion |
| Concluding Rites | Blessing, Dismissal |

Decision gateways capture seasonal variations (Lent skips Gloria and Alleluia; Solemnities always include Gloria).

## What Varies by Day

The Ordinary (fixed) parts of Mass stay the same. The Proper (variable) parts change daily:

- **Readings** — assigned by the Lectionary (3-year Sunday cycle A/B/C, 2-year weekday cycle I/II)
- **Responsorial Psalm** — paired with the First Reading
- **Gospel Acclamation** — Alleluia outside Lent; "Praise to you, Lord Jesus Christ..." during Lent
- **Gloria** — omitted during Advent and Lent (except Solemnities)
- **Liturgical color** — Purple (Advent/Lent), White (Christmas/Easter/feasts), Green (Ordinary Time), Red (martyrs/Pentecost/Palm Sunday)
- **Collect, Prayer over the Offerings, Prayer after Communion** — proper to each day

## Generation Service

The `services/mass-guide-agent/` generates these pamphlets automatically.

```
cd services/mass-guide-agent
npm run generate            # generates next 30 days
npm run generate -- --days 7   # or a custom range
```

The agent fetches liturgical calendar data (readings, season, color) for each date, renders the HTML template, and writes the output here. It is designed to run on a schedule (cron or CI) so the website always has upcoming pamphlets available.

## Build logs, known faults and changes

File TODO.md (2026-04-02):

- SPA: Accounts: There should be a detail page for each account so that I can click into it and see all the transactions that affected the account.  I should also be able to click those transactions to go to a transaction details page.  The chart of account accounts should link to account details.  The Balance Sheet accounts should also link to account details. The Journal account should also link to account details.
- SPA: Components.  The Batch (aka print job), can produce multiple components of various types.  Instead of Cap, Slipper, there should be multiple lines with the same print job reference.
- The print jobs is too much for a single line - allow for a form style entry.  the product being printed, including github commit hash, should be on each design in the print job.  these items will transfer over to the components page if everything is succesful.

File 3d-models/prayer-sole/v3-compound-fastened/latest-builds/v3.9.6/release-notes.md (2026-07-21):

# Prayer Sole v3.9.6 (compound fastened)

- Hex nut slide-in slot: thickness clearance now 0.2 mm (2.6 mm slot, matching the bumper bracket) — was 0.1 mm via `tolerance`, which pinched the nut.
- Nut clearance unified at 0.2 mm for across-flats and thickness (bumper-bracket `cap_nut_clearance` pattern); across-flats goes 5.75 → 5.7 mm.
- Hex pocket depth follows the same clearance (2.6 mm + ±0.5 mm `nut_pocket_x_extra`).

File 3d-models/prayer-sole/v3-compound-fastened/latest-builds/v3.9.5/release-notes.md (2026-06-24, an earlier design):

# Prayer Sole v3.9.5 (compound fastened)

- M3 bolt bores: 0.22 mm clearance (3.22 mm holes) for easier screw pass-through after print tolerance.
- Nut pockets: 0.25 mm clearance for easier hex nut seating.
- Guide pins: 0.05 mm radial hole clearance for easier peg fit at the cap/collar split.

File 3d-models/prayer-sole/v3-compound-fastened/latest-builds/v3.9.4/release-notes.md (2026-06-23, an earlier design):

# Prayer Sole v3.9.4 (compound fastened)

- M3 bolt bores: 0.2 mm clearance (3.2 mm holes) for easier screw pass-through after print tolerance.
- Cap socket-head pocket: `head_height` reduced to 2.5 mm for a shallower head recess.
- Guide pins: collar bores match the 4.0 mm post diameter (zero radial clearance).

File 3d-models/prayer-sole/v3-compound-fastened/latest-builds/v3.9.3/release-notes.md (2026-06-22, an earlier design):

# Prayer Sole v3.9.3 (compound fastened)

- Cap/collar lip split: move the +X long-side top lip overhangs from the collar to the cap; the collar keeps entrance-end (−X) overhangs only.
- M3 bolt bores: 3.0 mm nominal with 0.1 mm clearance (3.1 mm holes).

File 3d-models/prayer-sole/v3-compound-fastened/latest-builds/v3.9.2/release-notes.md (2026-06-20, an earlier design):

# Prayer Sole v3.9.2 (compound fastened)

- Cap: remove bolt-retainer split-face pockets and drop the optional PETG bolt retainer part from the kit.
- Cap fasteners: M3 bolt bores sized to 2.92 mm with zero clearance for a snugger screw fit.
- Cap head pocket: 2 mm collar-side chamfer from the socket-head recess down to shaft diameter, starting 0.1 mm +X from the pocket inner face.

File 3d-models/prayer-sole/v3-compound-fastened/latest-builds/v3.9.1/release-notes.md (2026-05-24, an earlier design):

# Prayer Sole v3.9.1 (compound fastened)

- Guide pins: 2 mm protrusion with 2 mm-radius domed tips; collar bores 4.1 mm deep at Ø 4.2 mm (0.1 mm radial clearance); hole aligned at split face.
- Cap head pocket: hulled 5.2 mm × 0.25 mm collar-side neck on the socket-head recess for a smoother boss transition.

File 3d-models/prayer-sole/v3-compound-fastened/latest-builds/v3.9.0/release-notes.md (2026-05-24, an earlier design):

# Prayer Sole v3.9.0 (compound fastened)

- Cap/collar split: outer side-wall strips in the cap zone (+X of split) move from the collar to the cap — the material from each cap boss outward to the shell Y edge now prints on the cap piece.
- Cap print solidity: side bands overlap each boss by `boss_dia/2`, cap body uses full `cap_width`, and boss X placement aligns with the side-wall strip so the mesh fuses above/below the bosses (no slicer gaps).

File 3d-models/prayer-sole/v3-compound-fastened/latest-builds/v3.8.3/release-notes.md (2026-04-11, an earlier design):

# Prayer Sole v3.8.3 (compound fastened)

- Cap socket-pocket ribs: clamp outer +X to `outer_extent` so struts do not extend past the printed end face; shorter −X nib and tunable `boss_support_socket_*` in `config.scad`.

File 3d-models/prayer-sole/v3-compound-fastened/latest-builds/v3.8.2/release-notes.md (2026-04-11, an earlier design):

# Prayer Sole v3.8.2 (compound fastened)

- Cap: built-in snap-off ribs in the socket-head pocket (+X) for clean sideways prints; optional boss-flank supports gated behind `boss_support_boss_flank_enable` in `config.scad`.

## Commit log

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2026-02-15 first prototype of a liquid build station = several issues to address
    [liquid-bait-station.3mf, liquid-bait-station.scad, liquid-bait-station.stl]
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2026-02-17 lowered profile a bit to get closer to 10mm, rolled radius back to 2, walls back to 4 loops. replaced rectangular ribs with semicylinders.
    [kneeler-boot-foot-33x19.stl, kneeler-boot-foot-48x19.stl, kneeler-boot-foot.scad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]
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2026-02-22 refactor: rename kneeler boot directories to descriptive classification scheme
    Replaced versioned naming (v1/v2/v3) with intent-based names:
    - kneeler-boots-v1 → kneeler-boot-monolithic-bonded
    - kneeler-boots-v2 → kneeler-boot-compound-bonded
    - kneeler-boots-v3 → kneeler-boot-compound-fastened
    Also renamed versioned 3mf files, updated workflow paths, fixed
    pre-existing kneeler-boot3-v3 typos in workflow, and updated readmes.
    [kneeler-boot-compound-bonded.3mf, kneeler-boot-compound-fastened.3mf, kneeler-boot-config.scad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]
2026-02-22 refactor: restructure repo with models/ hierarchy and add Next.js product site
    - Move all model directories under models/kneeler-replacement-parts/ and models/liquid-bait-station/
    - Update workflow paths in kneeler-boot-compound-fastened and liquid-bait-station validations
    - Scaffold Next.js 16 app in web/ with static export for GitHub Pages
    - Add product data JSON for all three kneeler boot designs
    - Add pages: home (product list), product detail, batch detail
    - Add web-deploy.yml workflow to build and deploy to GitHub Pages
    QR code URL format: /tektonology/products/{product-id}/batches/{batch-id}
    [kneeler-boot-compound-bonded.3mf, kneeler-boot-compound-fastened.3mf, kneeler-boot-config.scad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]
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2026-03-17 tightened tolerances and put a slot for the allen wrench to slip into
    [allen-wrench-handle.scad, kneeler-boot-compound-fastened.3mf]
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2026-03-21 replace perforated base plate with solid slab for faster print times
    Slicer infill handles material reduction more efficiently than
    many small holes, which cause excessive retractions and travel moves.
    [notecard-holder-bottom.scad, notecard-holder-bottom.stl]
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2026-03-21 add stop plate with chamfered filament holes and fix cross-section view
    Stop plate recessed at shaft top acts as PTFE tube shoulder with tapered
    holes from tube diameter down to filament diameter. Cross-section now
    cuts through model center by default.
    [ptfe-port-assembly.scad, ptfe-port-config.scad, ptfe-port-shaft.scad]
2026-03-21 add mirrored shaft and tune clearances for snug PTFE fit
    Mirror shaft so stop plates meet in the middle with filament holes
    connected. Tighten PTFE clearance (0.1mm) for push-fit grip, reduce
    collar clearance (0.15mm), and widen flange slot for barb pass-through.
    [ptfe-port-config.scad, ptfe-port-shaft.scad]
2026-03-21 fix clip slot to match tab thickness so barb catches on flange
    [ptfe-port-shaft.scad]
2026-03-21 move retaining clips from outer to inner collar edge with wider flange slots
    Repositions snap-fit clips to the inner hole edge of the collar so
    tabs sit in collar material flush with the shaft opening. Flange slots
    doubled in width toward the outer edge for barb pass-through clearance.
    [ptfe-port-assembly.scad, ptfe-port-collar.scad, ptfe-port-shaft.scad]
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2026-03-23 fix hex nut slot depth and flare to match pocket and shell wall
    Aligned pocket_depth with hex_nut_pocket (use tolerance instead of
    hardcoded 0.2) and derived slot_h from actual shell geometry instead
    of total_h, preventing the flare from cutting past the shell wall
    and removing nut retention material.
    [kneeler-boot-slipper.scad, kneeler-boot-slipper.stl]
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2026-03-24 redesign SPA: nav, products, STL viewers, projects progress
    - Split header into top bar (brand + auth icons) and nav bar (public left, authenticated right)
    - Add products index page with category grouping and 3D thumbnails
    - Add STL viewer components (single + assembly) using react-three-fiber
    - Add product pages: kneeler spacer, bolt drying rack; remove discontinued products
    - Redesign projects page with per-part progress bars, installation map links, and product thumbnails
    - Pew map: remove All Parts option, default to most-needed part, filter section stats by selected part
    - Project detail: add Date column to hardware table, uniform status badge widths
    - Rename Collar to Kneeler Bushing i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
    [allen-wrench-handle.stl, bolt-drying-rack-assembled-bolts.stl, bolt-drying-rack-assembled-rack.stl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]
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2026-03-28 add bolt/nut debug viz to assembly, fix hex pocket rotation for 45° slot
    - Add debug_bolts() (yellow) and debug_nuts() (green) to assembly preview
    - Wrap assembly in crosssection() for cross-section support
    - Rotate hex nut pocket 15° to align flats with 45° slide-in slot,
    preventing nut spin during tightening
    - Mirror-aware nut rotation (-15° on -Y side)
    [kneeler-boot-assembly.scad, kneeler-boot-config.scad, kneeler-boot-slipper.scad]
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2026-03-30 remove liquid-bait-station — moved to verminology repo
    Extracted all liquid-bait-station files (models, CI workflow) into a
    dedicated verminology repo with preserved git history. Replaced
    bait-station test fixture references with kneeler-bushing.
    [liquid-bait-station.3mf, liquid-bait-station.scad, liquid-bait-station.stl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]
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2026-04-02 PTFE tent port: tighter tubes, matched collar/flange, longer clips
    - Undersize PTFE bores slightly; collar_scale 1; flange_extra 6 mm
    - Taller barbs (lip_height 3.5 mm) and barb_shelf_offset_z for catch position
    - Regenerate collar and shaft STL exports
    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
    [ptfe-port-printer-tent-collar.stl, ptfe-port-printer-tent-config.scad, ptfe-port-printer-tent-shaft.stl]
2026-04-04 PTFE tent port: loosen tube clearance, widen flanges, reinforce clips
    Reduce tube interference from -0.05 to -0.02 per side for easier PTFE
    insertion. Increase flange_extra to 50mm for full canvas coverage.
    Thicken clip tabs (1.6→2.6mm) and raise barb shelf offset (1→3mm)
    for stronger snap-fit retention. Regenerated STLs.
    [ptfe-port-printer-tent-collar.stl, ptfe-port-printer-tent-config.scad, ptfe-port-printer-tent-shaft.stl]
2026-04-04 feat(kneeler-boot): stamp, export pipeline, and v3.8.1-prototype STLs
    Add top-face deboss stamp on the TPU insert (Tektonology / Foundation / Psalm)
    with print-stamp-config, stamp_generated sync, and bash/PowerShell export scripts.
    Include latest-builds layout, stamp variant JSON examples, CI workflow, and
    regenerated prototype STLs for insert, slipper, and cap.
    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
    [kneeler-boot-cap.stl, kneeler-boot-insert.scad, kneeler-boot-insert.stl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]
2026-04-04 build(kneeler-boot): add production STLs for v3.8.1
    Export to latest-builds/v3.8.1/ (KBCF_PRODUCTION=1): insert, slipper, cap.
    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
    [kneeler-boot-cap.stl, kneeler-boot-insert.stl, kneeler-boot-slipper.stl]
2026-04-05 Rehome Prayer Sole models under prayer-sole/ and rename v3 parts
    - Move kneeler-boot compound bonded/fastened into prayer-sole/v2 and v3; add v1-monolithic placeholder
    - v3: tread/collar/cap SCAD, config.scad, stamp-common, stamp-generated, stamp-config; collar_lip and export STLs renamed
    - Point CI, build-stls.mjs, and Claude GCODE_DIR at v3-compound-fastened
    - SPA: product copy, cap/collar/tread STL URLs, printSettings keys; PartCount uses tread/collar
    - Leave kneeler-bushing.stl unchanged (unrelated local diff reverted)
    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
    [assembly.scad, cap.scad, cap.stl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]
2026-04-05 Prayer Sole v3: fix stamp line3 to Prayer Sole; re-export STLs
    - stamp-config: Kneeler Soul -> Prayer Sole v3.8.1 on deboss line 3
    - Regenerate stamp-generated.scad and latest-builds v3.8.1 + prototype
    - Sync SPA public tread.stl
    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
    [cap.stl, collar.stl, stamp-generated.scad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]
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2026-04-07 Prayer Sole v3: custom tread stamp profiles and deeper deboss
    Move custom treads under v3-compound-fastened; replace pospi memorial with
    pospie single-file example. stamp-common gains info_stamp_profile arrays,
    optional info_stamp_gaps, per-line size/font/alignment, and profile-aware
    deboss layout. Raise default kbc_info_stamp_depth to 0.65 mm for all
    stamped parts. Add _stamp-profile-template for new jobs.
    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
    [_stamp-profile-template.scad, pospi-memorial-tread.scad, pospie-memorial-tread.scad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]
2026-04-11 Prayer Sole v3.8.2: cap socket-head pocket supports and STL export.
    Adds snap-off ribs inside the screw head pocket for sideways printing, splits bolt boolean for clean CSG, and bumps stamp to v3.8.2 with production STLs in latest-builds/v3.8.2.
    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
    [cap.scad, cap.stl, collar.stl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]
2026-04-11 Prayer Sole v3.8.3: socket rib length clamp and STL export.
    Clamps pocket strut +X to outer_extent, shortens nib, adds boss_support_socket_outer_inset and nib_past_plane. Regenerates stamp and production STLs in latest-builds/v3.8.3.
    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
    [cap.scad, cap.stl, collar.stl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]
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2026-04-15 Prayer Sole v3.8.4: boss edge support pillars and STL export.
    Replace pocket ribs and external tree supports with straight tapered
    pillars on the boss circumference, designed for X-down printing.
    Pillars sit within the boss footprint and snap off at the pocket ceiling.
    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
    [cap.scad, cap.stl, collar.stl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]
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2026-04-17 Prayer Sole v3.8.5: clip cap boss supports to outer_extent and STL export
    Wrap cap_boss_support_trees() in intersection clip so support brims and pillar bases do not extend past the cap +X face. Fixes disconnected first-layer islands when printing X-down.
    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
    [cap.scad, cap.stl, collar.stl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]
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2026-04-18 Prayer Sole v3.8.6: small caps, per-line spacing, halign fix for custom treads
    - stamp-common: add spacing parameter to profile rows and legacy per-line
    variables (info_stamp_lineN_smallcaps, info_stamp_lineN_spacing); wire
    spacing through _smallcaps_line and text() calls.
    - stamp-common: fix halign left/right offset direction under mirror transform
    so surface-relative alignment matches visual orientation.
    - stamp-common: remove eh (effective halign) flip -- pass user halign straight
    through after correcting translate offset.
    - Update _stamp-profile-template docs with spacing examples.
    - Bump version to v3.8.6; rebuild all STLs (default + 3 custom treads).
    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
    [_stamp-profile-template.scad, cap.stl, collar.stl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]
2026-04-18 Prayer Sole: JSON stamp profiles with per-segment underline, valign, and margin support
    Replace hardcoded OpenSCAD stamp arrays with JSON configs and a PowerShell
    prebuild pipeline (Convert-StampProfile.ps1) that generates .gen.scad files.
    Add per-segment underline and vertical alignment support in stamp-common.scad,
    per-row margin_top/margin_bottom spacing, and single-segment proportional font
    centering fix. Includes file watcher script and rebuilt STLs.
    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
    [_stamp-profile-template.scad, cap.stl, collar.stl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]
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2026-04-18 Prayer Sole: underline fine-tuning, valign pass-through, and row offset support
    Pass row valign directly to OpenSCAD text() for accurate visual alignment
    (fixes top/bottom flush). Add underline_scale, underline_x_offset, and
    underline_y_offset per-segment properties. Add row-level x_offset/y_offset
    for manual centering adjustment. Rebuild all STLs.
    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
    [_stamp-profile-template.scad, cap.stl, collar.stl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]
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2026-04-18 Prayer Sole: adjust Pospie Memorial spacing, fix sc warning for whitespace segments
    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
    [pospie-memorial-tread-body.stl]
2026-04-24 Prayer Sole v3: strengthen cap boss print supports and export cap STL.
    - Asymmetric inward brim, wider Y reach, thicker base bridges (config).
    - Multi-radius pillars on the curved boss face with tunable fractions.
    - Regenerate v3.8.6-prototype cap.stl from cap.scad.
    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
    [cap.scad, cap.stl, config.scad]
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2026-05-03 add kneeler bracket product with reference STL geometry
    Add Atwood-Hamlin kneeler bracket SCAD and rendered left/right STLs (solid pegs, boss collars, 3 countersunk screw holes). Add kneeler-bracket.json product page with purchase links to atwood-hamlin.com. Fix STL viewer 304 cache bug by appending a module-level cache-bust param. Hide Print Settings card when printSettings is empty.
    [kneeler-bracket-left.stl, kneeler-bracket-right.stl, kneeler-bracket.scad]
2026-05-03 update kneeler bracket geometry and product data
    Solid pegs (no hollow bore), 3 countersunk screw holes, narrower plate (34 mm), tan color (#C8B89A) to match nickel-plated steel. Correct product name to Kneeler Bracket with Atwood-Hamlin purchase links.
    [kneeler-bracket-left.stl, kneeler-bracket-right.stl, kneeler-bracket.scad]
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2026-05-13 bumper-bracket: chamfered screw bores, row along +Y at mid X
    Replace Y-spanning hull cuts with three coaxial cylinders on the sloped face. Holes share X at half the roof run with Z from hyp_z_at_x; Y positions use hole_y_frac. Add screw_chamfer_lip_mm; drop duplicate roof Z translate on the pattern.
    [bumper-parts.scad, config.scad]
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2026-05-24 Add press-fit guide pins at cap/collar split for alignment.
    1/8 in rods on the cap mate with interference holes in the collar (4 mm deep, Y tuned with guide_pin_y_inset).
    [cap.scad, collar.scad, config.scad]
2026-05-24 Tune collar nut pocket geometry and decouple bolt channel from pocket shift.
    Shift hex pockets/slots 2 mm toward cap while keeping bolt shaft bore depth fixed; remove slot flare, extend hex pocket ±0.5 mm on X.
    [collar.scad, config.scad]
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2026-05-24 Prayer Sole v3.9.0: bolt retainer, guide pins, and collar relief updates.
    Rename washer to cap-bolt-retainer with taller ring/prongs; tune guide pins to 4 mm slip-fit posts; widen collar lip relief to full shell width; regenerate production STLs.
    [bolt-retainer.stl, cap-bolt-retainer.scad, cap.scad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]
2026-05-24 Prayer Sole v3.9.1: guide pin fit, head pocket neck, production STLs.
    Shorter domed guide pins with slip-fit collar bores; hulled collar-side neck on cap head pockets; regenerate production export (=128).
    [bolt-retainer.stl, cap.scad, cap.stl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]
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2026-05-26 Align tread pockets with 9.8° E bevel and fix D-face slot stacking.
    Add simple rule-box preview mode, sloped polyhedron pockets (narrow tread flush on E, wider flange behind), and shell preview toggles for prism and screw holes.
    [bumper-bracket.scad, config.scad]
2026-05-26 Replace polyhedron cutters with hull frustums on the 9.8° E bevel.
    Solid rule box minus three sloped hull(CUBE) cutters (bevel, flange, tread) for reliable preview and meshing; turn off debug face labels in assembly preview.
    [assembly.scad, bumper-bracket.scad, config.scad]
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2026-05-27 Fix bumper assembly tread mate and group bracket preview as one unit.
    Orient tread to the E-bevel with correct Rx/Rz chain, center on bracket Z, and mate flange to the sloped groove; wrap shell, holes, and tread in a shared preview transform.
    [assembly.scad, config.scad]
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2026-05-29 Fix wood screw bores and countersinks on wedge hypotenuse.
    Align bores normal to the sloped face, anchor on the minkowski exterior, and
    taper countersinks wide at the outside narrowing into the wedge.
    [bumper-bracket.scad, config.scad]
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2026-05-30 Integrate tread retention cap as a flush recessed plug
    Replace the protruding cap slab with a flush "cube hull" recess milled
    into the -Z mouth below the seated treads. The cap is now built as the
    recess volume intersected with the beveled body solid, so it is solid
    across the slot opening (stops the treads), matches the existing bracket
    profile, and sits flush with the mouth instead of protruding. The recess
    floor stops at the wedge start in -Y, leaving the roof wedge and +X mount
    block intact. The single central M3x20 fastener now seats flush at the
    mouth, with the captive nut held behind the treads and fed by a +Y
    slide-in slot from the tread cavity. Both bracket and cap export as
    manifol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
    [assembly.scad, bumper-bracket.scad, cap.scad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]
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2026-06-01 Add bumper-bracket part and update Saint Stanislaus install data
    - Add bumper-bracket.json product definition (left + right variants)
    - Add bumper-bracket-left.stl and bumper-bracket-right.stl to public/stl
    - Mark bumper-bracket installed 2026-05-31 at er-1701
    - Add bumper-bracket needed to all pew kneelers across all sections
    - Fix 2028-05-03 install dates to 2026-05-03 (prayer-sole and other hardware)
    - Mark rows 18-19 prayer-sole installed 2026-05-31; rows 20-21 upcoming 2026-06-14
    - Correct frontType pewOnly to pew for west-main row-8 and west-rear rows 15,21,22,28
    - Add bumper-bracket needed to pillar-row pew kneelers in those corrected rows
    - Remove erroneous bumper-bracket entries fro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
    [bumper-bracket-left.stl, bumper-bracket-right.stl]
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2026-06-03 Capture cap nut with shorter slide-in slot and taller hex seat
    Decouple the nut slot and seat Z heights (prayer-sole collar pattern): the slide-in slot is now just nut thickness + clearance while the hex seat keeps the cap_nut_pocket_z_extra shoulders above and below, so the nut can't flop in the channel and is retained at the end of the slot.
    [bumper-bracket.scad, config.scad]
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2026-06-03 Reinforce mount block with flush pre-minkowski primitive
    Rename the -X mount-block rib to pew_mount_reinforce_* and add it as a
    pre-minkowski primitive so it rounds and welds flush to the block. It now
    runs the block's full Z height from the roof-wedge start out to the +Y
    front face, and is added before the hull cuts so the tread/cap/screw
    cutouts carve through it unchanged. Extend the E-bevel flush logic to stop
    at the reinforcement's -X face so it is not sliced.
    [bumper-bracket.scad, config.scad]
2026-06-03 Move QR sticker pocket to mount block +Y front face
    Relocate the QR-code recess from the -X rim to the mount block's +Y front
    face, cutting inward (-Y). Center it on the full front face (block + flush
    -X reinforcement) so the 1" tile fits, and position it 3 mm below the +Z
    (pew) top via qr_pocket_top_margin_mm. Offsets now run along bracket X/Z.
    [bumper-bracket.scad, config.scad]
2026-06-03 Plane mount block pew face flush to fix pew interference
    The mount block's +X face overshot the pew leg inner face by ~1 mm (~2 mm
    with the minkowski rounding), interfering with the pew. Add a half-space
    trim at the pew inner-face plane so the pew-facing face is flat and flush
    (no overshoot, no rounding), gated by pew_mount_block_pew_face_flush_enabled.
    Update the QR pocket centering to track the trimmed +X edge.
    [bumper-bracket.scad, config.scad]
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2026-06-04 Flush cap to undercut and add pew-side cap guide pins
    Carve the cap with the same pre-mink undercut so its pew face is flush (no proud overhang). Add domed +X guide pins on the cap with chamfered clearance bores in the bracket for tilt-and-pivot seating.
    [bumper-bracket.scad, cap.scad, config.scad]
2026-06-04 Pull cap pew-side face flush with mount-block bridge
    Bound the tread cap's +X recess edge to the mount-block -X face
    (tread_cap_recess_x_hi_mm) instead of the symmetric core rim, so the
    cap no longer reaches out under the protruding bridge. The pew-side
    guide-post edge now runs flush across its full length, and the pin
    bores reference the same bound.
    [bumper-bracket.scad, config.scad]
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2026-06-05 Move side screw chamfer to entry face and free bore Y/X position
    Chamfer relocated from the +X pew-flush exit to the entry face so
    the screw head seats on the accessible side. bore_y_mm is now a
    free variable (no longer auto-follows bore_x). Angle comment updated
    to reflect that a negative angle tilts the bore toward +Y.
    [bumper-bracket.scad, config.scad]
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2026-06-10 Narrow bumper bracket 5 mm on the -X face (face B)
    Fold the trim directly into the shell envelope anchor parameters so no
    extra clip module is needed. shell_envelope_inset_lx_mm is now
    corner_r + 5 (was corner_r), shell_envelope_core_lx_mm is derived as
    the span from that inset to the fixed +X rim, and
    shell_envelope_wedge_xr_lx_mm() is pinned to shell_extent_qr_wedge_mm
    - corner_r so the +X rim is independent of the -X inset.
    [config.scad]
2026-06-10 Trim shell Z span 5 mm on each face (face C and face D)
    Add shell_z_inset_mm = 5 and fold it into shell_extent_tread_pew_mm
    so both the +Z and -Z faces shorten symmetrically. All downstream
    values (bracket faces, tread pocket positions, screw hole spacing,
    E-bevel, cap recess) derive from shell_extent_tread_pew_mm and
    cascade automatically.
    [config.scad]
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2026-06-10 Nudge tread pockets +Z and clear kneeler plate in mount-block pocket
    - Add tread_pocket_z_nudge_mm (=2) shifting all tread pocket hulls (flange
    groove + both core pockets) along +Z; the -Z mouth stays clamped open and
    the +Z seating end lifts. Thread the same nudge through the tread ghost
    (assembly_tread_mate_bracket_z_mm) and the cap's seated-tread reference
    (tread_seated_bracket_z_min_mm) so pockets, preview ghosts, and cap stay
    consistent.
    - Give the perpendicular +X-face mount-block pocket clearance over the kneeler
    plate (pew_mount_block_pocket_y_len_mm 32 -> 32.67) so the steel plate no
    longer interferes; verified the bracket-kneeler intersection is empty.
    - Tweak assembl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
    [bumper-bracket.scad, config.scad]
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2026-06-12 Fix bumper-bracket preview emit and rebuild v2.0 STLs.
    Use BUMPER_BRACKET_INCLUDED_BY so bumper-bracket.scad renders when opened
    directly, and export split bracket and tread-carriage parts at full quality.
    [assembly.scad, bumper-bracket-left.stl, bumper-bracket-right.scad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]
2026-06-16 Fix partial cap screw-head socket on fused bracket export.
    Union the integrated cap into the body before subtracting tread_cap_bolt_hole() so the recess is not clipped by cap intersect shell at the tread-slot mouth.
    [bumper-bracket.scad]
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2026-06-18 Publish bumper-bracket v2.1 on the product page and fix kneeler-bracket purchase link.
    The SPA was still serving v1.0 bumper-bracket STLs; update downloads and metadata for the v2.1 split design including tread carriages. Point kneeler-bracket buyers to Atwood-Hamlin's kneeler-brackets page instead of separate arms/hardware links.
    [bumper-bracket-left.stl, bumper-bracket-right.stl, tread-carriage-left.stl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]
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2026-06-20 Remove cap bolt retainer pockets and tighten M3 bolt hole fit.
    Drop the split-face washer sockets now that retainers are not seated in the cap, and size bolt bores to 2.92 mm with zero clearance for a snugger screw fit.
    [cap-bolt-retainer.scad, cap.scad, config.scad]
2026-06-20 Replace cap head-pocket hull with a shaft-sized chamfer.
    Taper the socket-head recess into the bolt bore over 2 mm, offset 0.1 mm +X from the pocket inner face, and match the chamfer end to bolt_hole_dia.
    [cap.scad, config.scad]
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2026-06-22 Adjust Prayer Sole M3 bolt hole clearance and rebuild cap/collar STLs.
    Set bolt bores to 3.0 mm nominal with 0.1 mm clearance and regenerate the v3.9.2 cap and collar exports.
    [cap.stl, collar.stl, config.scad]
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2026-06-23 Tune Prayer Sole fastener and guide-pin fits.
    Increase M3 bolt hole clearance to 0.2 mm, shallow the cap head pocket to 2.5 mm, and size guide-pin bores to the 4.0 mm post with zero radial clearance.
    [config.scad]
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2026-07-18 Size bumper-bracket screw bores for #10 and add QR alignment frame; build v2.2.
    All four wood-screw holes now share one 5.75 mm clearance diameter (the 3
    angled roof bores were still #8-sized and bound on #10 screws; the side
    screw bore now derives from the same parameter). Adds a 0.5 mm engraved
    frame around the QR sticker recess for sticker alignment.
    [bumper-bracket-assembly-carriage.stl, bumper-bracket-assembly-shell.stl, bumper-bracket-assembly-tread-1.stl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]
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
